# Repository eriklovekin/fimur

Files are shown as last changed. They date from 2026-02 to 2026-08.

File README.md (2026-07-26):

# Fused Inertial Measurement Unit aRray (FIMUR)
Can the performance of high-cost IMUs be matched through the fusion of a large array of MEMS IMUs?

## Coordinate Frames
### Sensor (S)
The S frame is the frame in which the sensor outputs measurements.

### Filter (F)
The F frame is the frame in which the output of the filter is represented. The origin and orientation of each IMU must be initialized in this frame. 
    Origin: position of the S origin of the IMU as (x_F, y_F, z_F)
    Rotation: Direction cosine matrix from IMU S frame to F frame

### Wake (W)
The W frame is an inertial frame colocated with the F frame at filter startup (wake). It does not move with the sensor, and is the frame in which position estimates are represented.

### ENU (L)
The ENU frame is an inertial frame with origin colocated with the Filter frame origin.

## Filters

### 1: Intuitive Filter
Naive filter that implements my intuition about how a filter should work

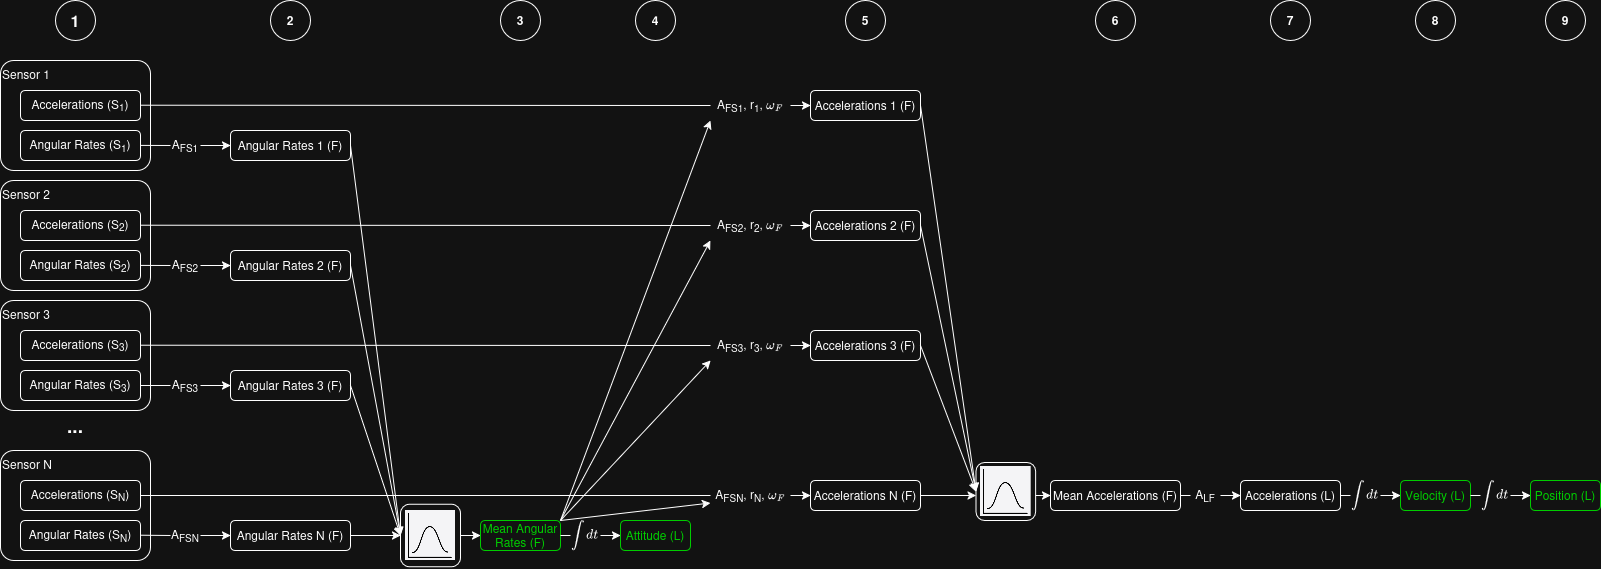
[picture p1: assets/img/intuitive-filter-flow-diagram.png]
Intuitive Filter Flow Diagram

*Figure 1: Flow diagram of Intuitive Filter*

### Dependencies

## Python
Running with python 3.12.3
Ensure the following libraries are installed using `pip install <library>`
- serial
- pyserial
- pandas
- numpy
- pyqtgraph
- pyside6
- allantools

### PyQt
- `sudo apt update`
- `sudo apt install libxcb-cursor0`

## References
1 [Interactive Kalman Filter Tutorial](https://arthurlovekin.com/interactive-kalman-filter/index.html)

2 [Extended Kalman Filter](https://mwrona.com/posts/attitude-ekf/)

3 Sarabandi, S; Thomas, F - Accurate Computation of Quaternions from Rotation Matrices

4 [Rotation Quaternions, and How to Use Them](https://danceswithcode.net/engineeringnotes/quaternions/quaternions.html)

5 [AHRS Complimenatary Filter](https://ahrs.readthedocs.io/en/latest/filters/complementary.html)

6 [Building a Virtual Gyro](https://www.nxp.com/company/about-nxp/smarter-world-blog/BL-BUILDING-VIRTUAL-GYRO)

7 [Gauss Markov Theorem](https://www.statlect.com/fundamentals-of-statistics/Gauss-Markov-theorem)

8 [Sensor Fusion for Distributed Inertial Measurement Units](https://hollydinkel.github.io/assets/pdf/AAS2025.pdf)

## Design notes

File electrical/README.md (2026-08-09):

# FIMUR Electrical
## Naming Convention
Each board has a 3-digit version number: A.B.C
A - major version number
B - board type. 
    1 is ICM20948 i2c breakout;
    2 is i2c multiplexer breakout and esp32 interface
C - minor version number

## IMC20948 Breakout (x.1.x)
I2C Breakout for two ICM20948 9-axis IMUs.
U2 (sensor on the left when text is upright) has I2C address 0x68. U3 has address 0x69.

### Exposes
- I2C bus
    two connectors to allow daisychaining
- pullup pins
    One and only one device on the bus must jump the pullup pins to allow for correct logic operation.
- FSYNC pins
    Future Work: should be able to daisychain all IMUs on this line to synchronize sample times

### v0.1.1
Works. 
- should add some capacitors to the 1.8V power supply as per spec sheet
- print IMU addresses next to them for easy ID

## Multiplexer Interface (x.2.x)
Connects ESP32 with TCA9548A I2C multiplexer.

### Exposes
- i2c bus upstream of multiplexer
    two connectors to allow daisychaining
- pullup pins for upstream i2c bus
    One and only one device on the upstream bus must jump the pullup pins to allow for correct logic operation.
- address pins for multiplexer
    each multiplexer on the upstream i2c bus must have a unique address. Addresses range from 0x70 to 0x77. The default address w/o any address pins driven is 0x70.
- eight multiplexed i2c channels downstream of the multiplexer. 
    These act as their own bus, so devices with the same address can be used if on different channels.

The board uses 3.3V I2C logic supplied directly from the ESP32.

### 0.2.1
Bad: made ESP32 get very hot. Do not use.

### 0.2.2
Fixed issues with 0.2.1. Tested with two IMUs connected to the same and differet channels.

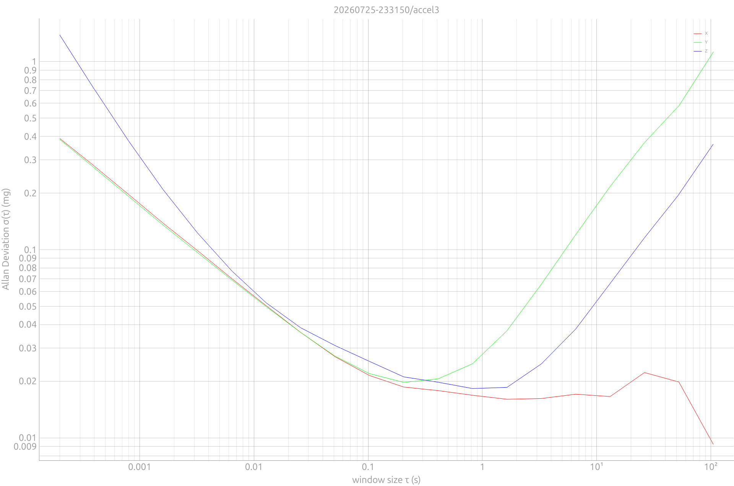
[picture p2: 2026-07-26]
assets/img/allan/20260725-233150/allan_accel3.png

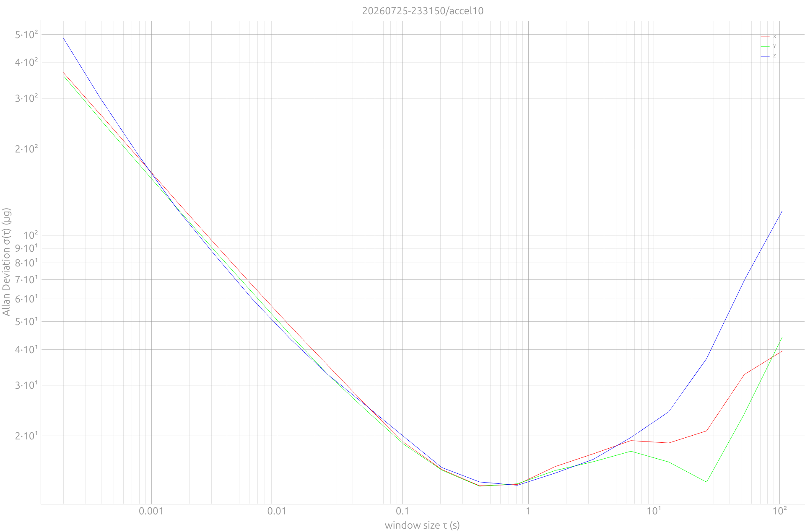
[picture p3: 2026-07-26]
assets/img/allan/20260725-233150/allan_accel10.png

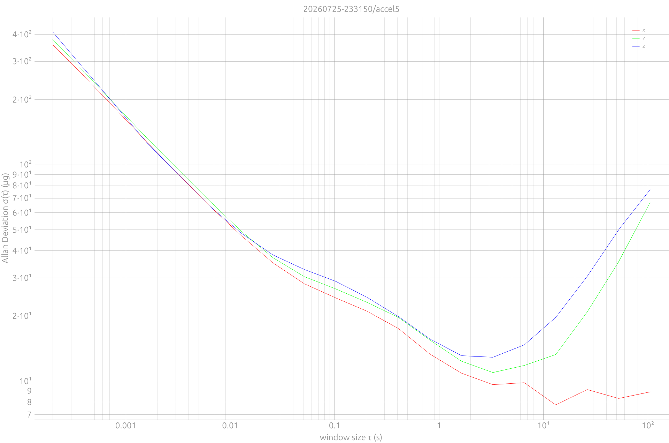
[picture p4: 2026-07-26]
assets/img/allan/20260725-233150/allan_accel5.png

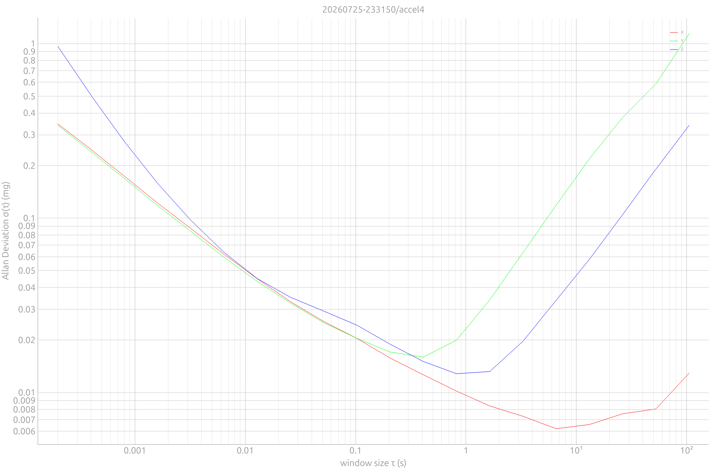
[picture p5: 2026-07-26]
assets/img/allan/20260725-233150/allan_accel4.png

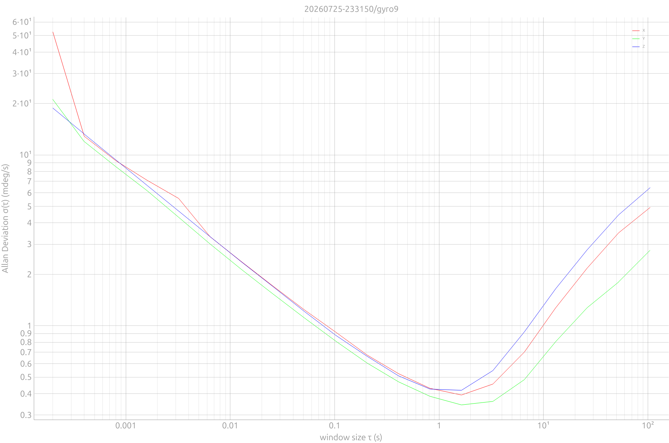
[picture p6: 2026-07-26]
assets/img/allan/20260725-233150/allan_gyro9.png

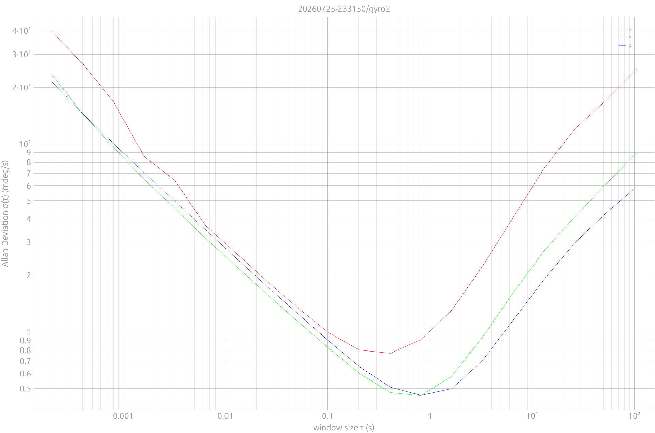
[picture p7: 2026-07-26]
assets/img/allan/20260725-233150/allan_gyro2.png

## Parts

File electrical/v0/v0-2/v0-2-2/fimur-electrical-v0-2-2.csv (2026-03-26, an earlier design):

Designator | Footprint | Comment
J7,J8,J12,J15,J10,J9,J11,J6,J14,J13 | JST_SH_SM04B-SRSS-TB_1x04-1MP_P1.00mm_Horizontal | XY-SM04B-SRSS-TB
J5,J4,J3 | PinHeader_1x03_P2.54mm_Vertical | HC-PZ254-11.5L-1x3PZ
J2,J1 | PinSocket_1x16_P2.54mm_Vertical | 2541FV-16P-B
R1,R3,R2 | R_1206_3216Metric | 10k
U1 | TSSOP-24_4.4x7.8mm_P0.65mm | TCA9548APWR
J16 | PinHeader_1x02_P2.54mm_Vertical | HC-PZ254-11.5L-1x2PZ

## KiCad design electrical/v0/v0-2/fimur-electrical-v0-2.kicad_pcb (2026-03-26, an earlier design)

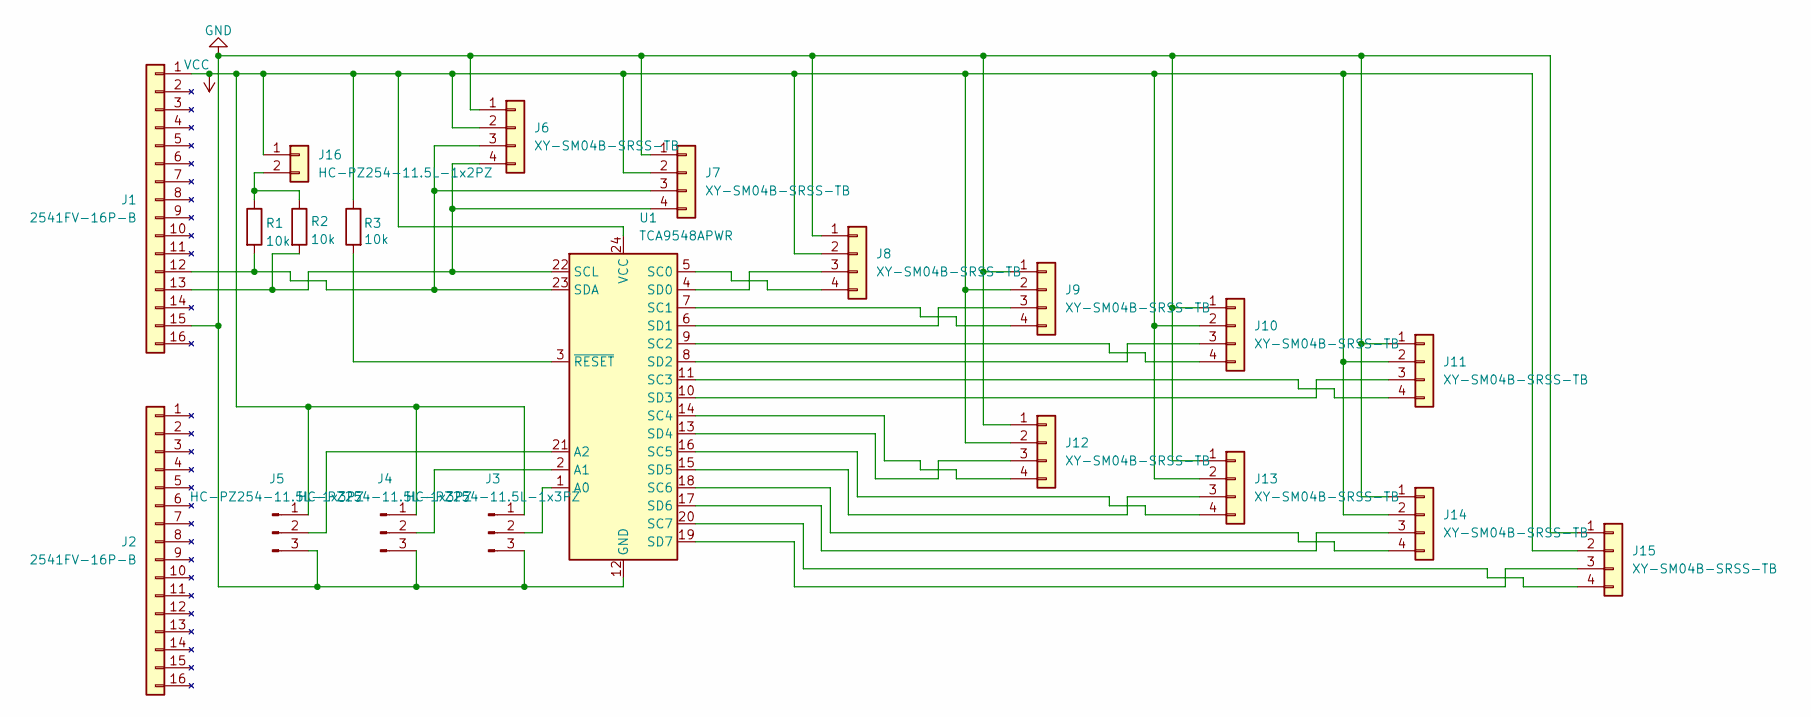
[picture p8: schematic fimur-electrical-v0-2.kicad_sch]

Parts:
J1, J2: 2541FV-16P-B; PinSocket_1x16_P2.54mm_Vertical
J3, J4, J5: HC-PZ254-11.5L-1x3PZ; PinHeader_1x03_P2.54mm_Vertical
J6, J7, J8, J9, J10, J11, J12, J13, J14, J15: XY-SM04B-SRSS-TB; JST_SH_SM04B-SRSS-TB_1x04-1MP_P1.00mm_Horizontal
J16: HC-PZ254-11.5L-1x2PZ; PinHeader_1x02_P2.54mm_Vertical
R1, R2, R3: 10k; R_1206_3216Metric
U1: TCA9548APWR; TSSOP-24_4.4x7.8mm_P0.65mm

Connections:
GND: J1.15 (G), J3.3, J4.3, J5.3, J6.1, J7.1, J8.1, J9.1, J10.1, J11.1, J12.1, J13.1, J14.1, J15.1, U1.12 (GND); also elsewhere on the board
unnamed: J1.12 (2), J6.3, J7.3, R1.2, U1.23 (SDA)
unnamed: J1.13 (3), J6.4, J7.4, R2.2, U1.22 (SCL)
unnamed: J3.2, U1.1 (A0)
unnamed: J4.2, U1.2 (A1)
unnamed: J5.2, U1.21 (A2)
unnamed: J8.3, U1.4 (SD0)
unnamed: J8.4, U1.5 (SC0)
unnamed: J9.3, U1.6 (SD1)
unnamed: J9.4, U1.7 (SC1)
unnamed: J10.3, U1.8 (SD2)
unnamed: J10.4, U1.9 (SC2)
unnamed: J11.3, U1.10 (SD3)
unnamed: J11.4, U1.11 (SC3)
unnamed: J12.3, U1.13 (SD4)
unnamed: J12.4, U1.14 (SC4)
unnamed: J13.3, U1.15 (SD5)
unnamed: J13.4, U1.16 (SC5)
unnamed: J14.3, U1.17 (SD6)
unnamed: J14.4, U1.18 (SC6)
unnamed: J15.3, U1.19 (SD7)
unnamed: J15.4, U1.20 (SC7)
unnamed: J16.2, R1.1, R2.1
unnamed: R3.2, U1.3 (~RESET)
VCC: J1.1 (3V3), J3.1, J4.1, J5.1, J6.2, J7.2, J8.2, J9.2, J10.2, J11.2, J12.2, J13.2, J14.2, J15.2, J16.1, R3.1, U1.24 (VCC); also elsewhere on the board

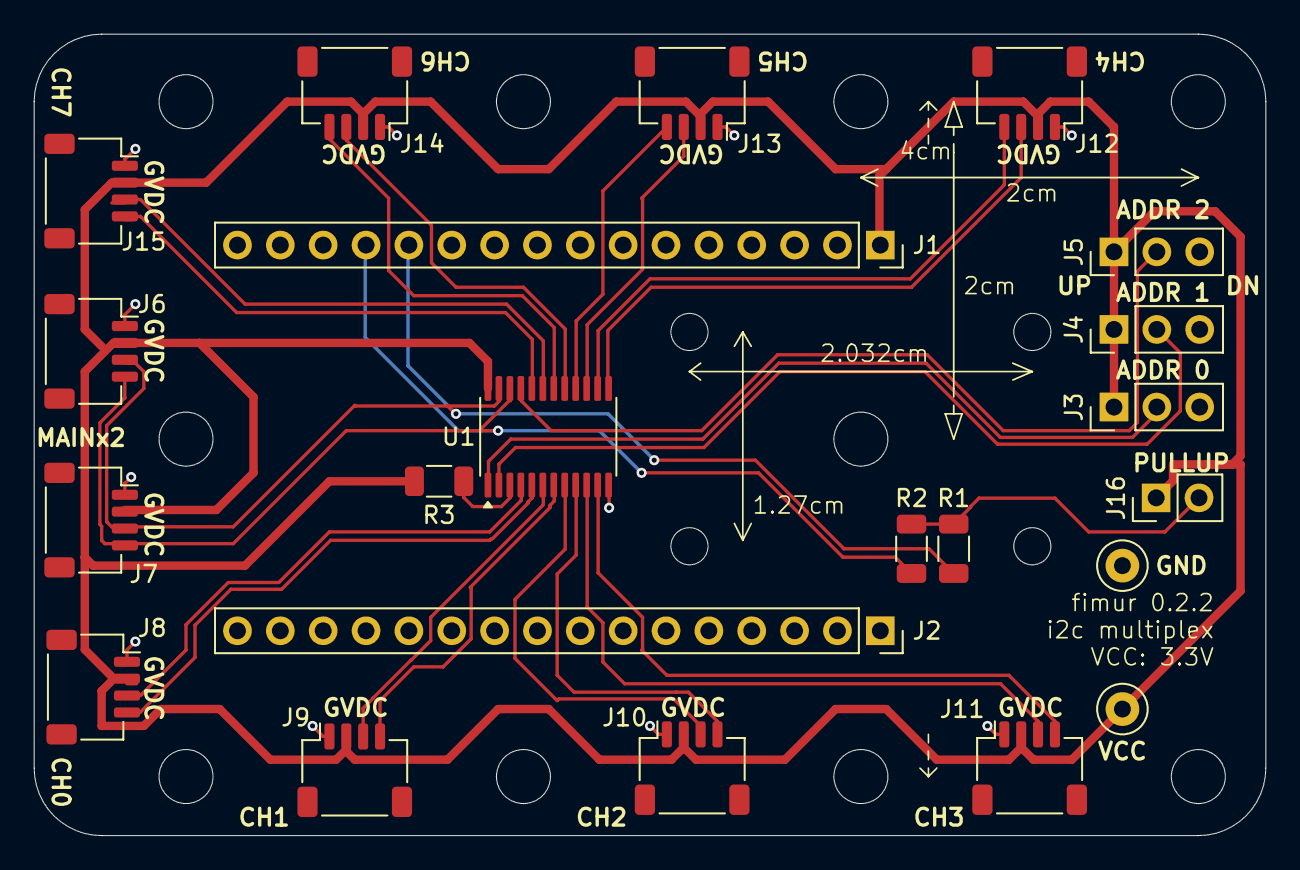
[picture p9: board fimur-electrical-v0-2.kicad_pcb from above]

Board: 2 copper layers, 73.0 x 47.5 mm, 22 parts (0 on the bottom side), 25 nets.

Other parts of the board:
GND: TestPoint_Loop_D1.80mm_Drill1.0mm_Beaded
VCC: TestPoint_Loop_D1.80mm_Drill1.0mm_Beaded

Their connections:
GND: GND.1; also elsewhere on the board
VCC: VCC.1; also elsewhere on the board

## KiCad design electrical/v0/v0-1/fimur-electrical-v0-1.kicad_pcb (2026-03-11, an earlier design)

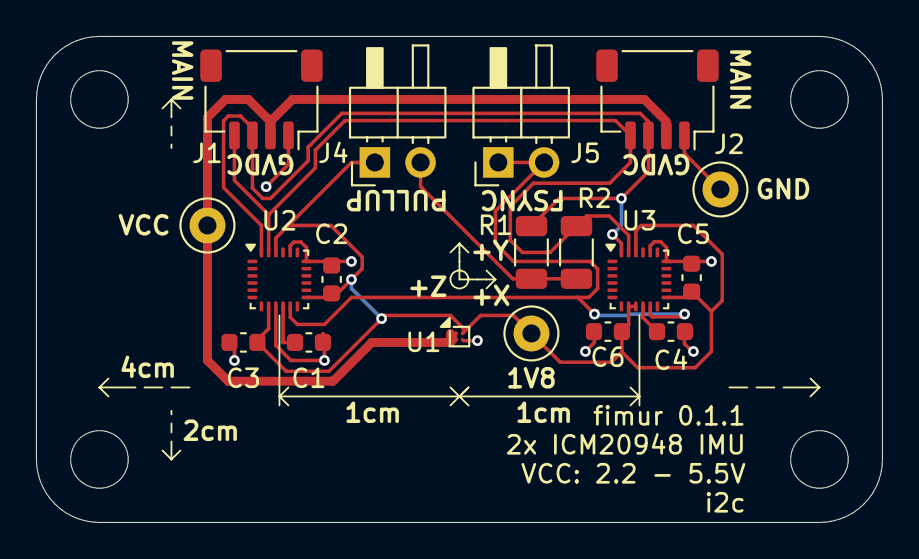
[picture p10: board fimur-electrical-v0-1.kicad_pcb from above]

Board: 2 copper layers, 47.0 x 27.0 mm, 18 parts (0 on the bottom side), 9 nets.

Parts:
1V8: TestPoint_Loop_D1.80mm_Drill1.0mm_Beaded
C1, C2, C3, C4, C5, C6: 0.1 uF; C_0603_1608Metric
GND: TestPoint_Loop_D1.80mm_Drill1.0mm_Beaded
J1, J2: Conn_01x04_Pin; JST_SH_SM04B-SRSS-TB_1x04-1MP_P1.00mm_Horizontal
J4, J5: Conn_01x02; PinHeader_1x02_P2.54mm_Horizontal
R1, R2: 10k; R_1206_3216Metric
U1: NCP163AFCS180T2G; WLCSP-4_0.64x0.64mm_Layout2x2_P0.35mm
U2, U3: ICM-20948; InvenSense_QFN-24_3x3mm_P0.4mm
VCC: TestPoint_Loop_D1.80mm_Drill1.0mm_Beaded

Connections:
GND: C1.2, C2.2, C3.2, C4.2, C5.2, C6.2, GND.1, J1.1, J2.1, U1.B2 (GND), U2.9 (SDO/AD0), U2.18 (GND), U2.20 (GND), U3.18 (GND), U3.20 (GND)
unnamed: J1.2, J2.2, U1.A1 (VIN), U1.B1 (EN), VCC.1
unnamed: J1.3, J2.3, R1.2, U2.24 (SDA/SDI), U3.24 (SDA/SDI)
unnamed: J1.4, J2.4, R2.2, U2.23 (SCL/SCLK), U3.23 (SCL/SCLK)
unnamed: 1V8.1, C2.1, C3.1, C5.1, C6.1, J4.1, U1.A2 (VOUT), U2.8 (VDDIO), U2.13 (VDD), U2.22 (~CS), U3.8 (VDDIO), U3.9 (SDO/AD0), U3.13 (VDD), U3.22 (~CS)
unnamed: J4.2, R1.1, R2.1
unnamed: J5.1, J5.2, U2.11 (FSYNC), U3.11 (FSYNC)
unnamed: C1.1, U2.10 (REGOUT)
unnamed: C4.1, U3.10 (REGOUT)

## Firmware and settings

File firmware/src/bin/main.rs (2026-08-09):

#![no_std]
#![no_main]
#![deny(
    clippy::mem_forget,
    reason = "mem::forget is generally not safe to do with esp_hal types, especially those \
    holding buffers for the duration of a data transfer."
)]
#![deny(clippy::large_stack_frames)]

use defmt::{
    info,
};
// use esp_hal::lp_core::LpCoreClockSource;
use esp_println::println;
use esp_hal::clock::CpuClock;
use esp_hal::main;
use esp_hal::rmt::Rmt;
use esp_hal::time::{Duration, Instant, Rate};
use core::cell::RefCell;
use core::fmt::Write;
use heapless::String;
use embedded_hal_bus::i2c::RefCellDevice;
use esp_hal_smartled::{SmartLedsAdapter, smart_led_buffer};
use smart_leds::{RGB8, SmartLedsWrite as _};
use {esp_backtrace as _, esp_println as _};

use esp_hal::i2c::master::{I2c, Config};

use icm20948::Icm20948;
use imu_traits::{Imu, ImuWithAdustableScale};
use fimur::filter::{
    Filter,
};

use xca9548a::{Xca9548a, SlaveAddr};
// This creates a default app-descriptor required by the esp-idf bootloader.
// For more information see: <https://docs.espressif.com/projects/esp-idf/en/stable/esp32/api-reference/system/app_image_format.html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>
esp_bootloader_esp_idf::esp_app_desc!();

#[allow(
    clippy::large_stack_frames,
    reason = "it's not unusual to allocate larger buffers etc. in main"
)]
#[main]
fn main() -> ! {
    info!("startup");

    let mut timestamp: u64 = 0;
    // let loop_duration_us: u32 = 200; 

    let config = esp_hal::Config::default().with_cpu_clock(CpuClock::max());
    let _peripherals = esp_hal::init(config);
    let rmt = Rmt::new(
        _peripherals.RMT, Rate::from_mhz(80)).unwrap();

    let i2c_config = Config::default();
    let i2c = I2c::new(_peripherals.I2C0, i2c_config)
        .expect("Failed to initialize i2c")
        .with_sda(_peripherals.GPIO2)
        .with_scl(_peripherals.GPIO3);
    // RefCell needed so multiple multiplexers or I2C devices can share the same bus
    let i2c_bus = RefCell::new(i2c);

    let aligned: [[f32;3];3]= [
        [1.0, 0.0, 0.0],
        [0.0, 1.0, 0.0],
        [0.0, 0.0, 1.0]
    ];

    let cots_aligned: [[f32;3];3]= [
        [ 0.0, -1.0,  0.0],
        [-1.0,  0.0,  0.0],
        [ 0.0,  0.0, -1.0]
    ];

    // let switch_address = SlaveAddr::Alternative(false,false,false);
    let switch_address = SlaveAddr::default();
    let i2c_switch = Xca9548a::new(
        RefCellDevice::new(&i2c_bus), switch_address);
    let parts = i2c_switch.split();
    
    // RefCell needed so multiple devices can share the same channel of the multiplexer
    let ch0_bus = RefCell::new(parts.i2c0);
    let ch1_bus = RefCell::new(parts.i2c1);
    let ch2_bus = RefCell::new(parts.i2c2);
    let ch3_bus = RefCell::new(parts.i2c3);
    let ch4_bus = RefCell::new(parts.i2c4);
    let ch5_bus = RefCell::new(parts.i2c5);
    // let ch6_bus = RefCell::new(parts.i2c6);
    // let ch7_bus = RefCell::new(parts.i2c7);

    let imu1 = Icm20948::new_with_mount(
        RefCellDevice::new(&ch0_bus),0x68,
        [-0.01,0.0,0.0],
        aligned);
    let imu2 = Icm20948::new_with_mount(
        RefCellDevice::new(&ch0_bus),0x69,
        [0.01,0.0,0.0],
        aligned);

    let imu3 = Icm20948::new_with_mount(
        RefCellDevice::new(&ch1_bus),0x68,
        [-0.01,0.0,-0.0115],
        aligned);
    let imu4 = Icm20948::new_with_mount(
        RefCellDevice::new(&ch1_bus),0x69,
        [0.01,0.0,-0.0115],
        aligned);

    let imu5 = Icm20948::new_with_mount(
        RefCellDevice::new(&ch2_bus),0x68,
        [-0.01,0.0,-0.023],
        aligned);
    let imu6 = Icm20948::new_with_mount(
        RefCellDevice::new(&ch2_bus),0x69,
        [0.01,0.0,-0.023],
        aligned);

    let imu7 = Icm20948::new_with_mount(
        RefCellDevice::new(&ch3_bus),0x68,
        [-0.01,0.0,-0.0345],
        aligned);
    let imu8 = Icm20948::new_with_mount(
        RefCellDevice::new(&ch3_bus),0x69,
        [0.01,0.0,-0.0345],
        aligned);

    let imu9 = Icm20948::new_with_mount(
        RefCellDevice::new(&ch4_bus),0x68,
        [-0.01,0.0,-0.0460],
        aligned);
    let imu10 = Icm20948::new_with_mount(
        RefCellDevice::new(&ch4_bus),0x69,
        [0.01,0.0,-0.0460],
        aligned);

    let imu11 = Icm20948::new_with_mount(
        RefCellDevice::new(&ch5_bus),0x68,
        [0.0,-0.03,0.0],
        cots_aligned);
    let imu12 = Icm20948::new_with_mount(
        RefCellDevice::new(&ch5_bus),0x69,
        [0.0,-0.03,-0.0115],
        cots_aligned);


    let mut f = Filter::new([
        imu1, imu2, imu3, imu4, imu5, imu6, 
        imu7, imu8, imu9, imu10, imu11, imu12
        ]);
    f.init();
    
    for s in 0..f.get_n_sensors() {
        f.sensor(s).set_accelerometer_scale(3)
            .expect("failed to set accelerometer range");
        f.sensor(s).set_gyroscope_scale(3)
            .expect("failed to set gyroscope range");
        f.sensor(s).set_origin_f([0.0, 0.0, 0.01]);
        f.sensor(s).set_rotation_dcm_s2f([  
            [1.0, 0.0, 0.0],
            [0.0, 1.0, 0.0],
            [0.0, 0.0, 1.0]]);
    }
    
    let mut led_buf = smart_led_buffer!(1);
    let mut led = SmartLedsAdapter::new(
        rmt.channel0, _peripherals.GPIO8, &mut led_buf);
    const LEVEL: u8 = 10;
    let mut color = RGB8::default();
    color.r = LEVEL;

    let mut output: String<8192> = String::new();

    info!("reading imu data");
    loop {
        led.write([color].into_iter()).unwrap();
        let loop_start = Instant::now();
        // while delay_start.elapsed() < Duration::from_micros(loop_duration_us as u64) {}

        // Read all sensors
        f.read_all();

        // Estimate virtual measurements
        f.colocated_coaligned_avg();
        // f.f_frame_avg();

        output.clear();
        write!(output,"{},",timestamp).ok();
        write!(output,"{}", f.report_raw()).ok();
        write!(output,"{}", f.report_virtual_meas()).ok();
        println!("{}",output);
        let tmp = color.r;
        color.r = color.b;
        color.b = color.g;
        color.g = tmp;

        let loop_end = Instant::now();
        let elapsed: Duration = loop_end - loop_start;
        timestamp += elapsed.as_micros();
    }
}

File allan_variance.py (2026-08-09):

import pandas as pd
import numpy as np
import pyqtgraph as pg
from pyqtgraph.Qt import QtWidgets, QtCore
import pyqtgraph.exporters
import sys
import os
import signal
import allantools

def compute_allan_variance(dt,x):
    N = len(x)
    avar = []
    tau = []
    vals = []
    n = 1
    r = 1.1
    while n < N//2:
        vals.append(n)
        n_next = n*r
        n = int(np.round(max(n_next, n+1)))

    j=0
    for n in vals:
        print(f"{100*j/len(vals):.2f}% complete")
        A = 1/(2*n**2*dt**2*(N-2*n))
        d = x[2*n:]-2*x[n:-n] + x[:-2*n]
        avar.append(A*np.sum(d**2))

        tau.append(n*dt) 
        j+=1
    return tau, avar

if __name__ == "__main__":
    path = "./logs/"
    timestamp = "20260808-235938/"
    # timestamp = "20260725-233150/"
    # timestamp = "20260807-052335/"
    sensor = ["accel", "gyro"]
    units =  ["m/s2", "rad/s"]
    axis = ["x","y","z"]
    color = ["r","g","b"]
    N_IMUS = 13

    index = pd.MultiIndex.from_product(
    [range(1, N_IMUS+1), ["accel", "gyro"], ["x", "y", "z"]],
    names=["imu", "sensor", "axis"]
    )
    superDf = pd.DataFrame(index=index, columns=["tau", "B"], dtype=float)

    # conversion from min allan deviation to bias instability
    C = 1/np.sqrt(2*np.log(2)/np.pi) # per IEEE-STD-952-1997 Annex C 

    dt_diag = []

    app = QtWidgets.QApplication(sys.argv)
    windows = []

    for i in range(0,N_IMUS):
        for j in range(len(sensor)):
            full = path+timestamp+sensor[j]+str(i+1)+".csv"
            print(f"loading {full}")
            df = pd.read_csv(f"{full}")

            z_numeric = pd.to_numeric(df["z"], errors="coerce")
            bad_mask = z_numeric.isna() & df["z"].notna()  # failed to parse, but wasn't already NaN/empty
            # print(df.loc[bad_mask, "z"])
            
            nan_counts = df.isna().sum()
            if nan_counts.any():
                print(df.isna().sum())  # NaN count per column
                nan_rows = df[df.isna().any(axis=1)]
                print(nan_rows.head(20))
                print(f"first NaN at row: {nan_rows.index.min() if len(nan_rows) else 'none'}")
            # dt = (df["t_us"][2] - df["t_us"][1])/1e6
            dt = (df["t_us"][-1] - df["t_us"][1])/(1e6*(df["t_us"].size()-1))
            dt_diag = np.diff(df["t_us"])
            mean_dt = np.mean(dt_diag)
            std_dt = np.std(dt_diag)
            w = pg.GraphicsLayoutWidget(show=True, title=f"Loop Time histogram - {timestamp}{sensor[j]}{i+1}")
            w.resize(1200, 800)
            p1 = w.addPlot()
            p1.setTitle(f"Loop Time histogram - {timestamp}{sensor[j]}{i+1}, mean: {mean_dt}, std: {std_dt}")
            # p1.setLabel('left', '', units="s")
            p1.setLabel('bottom', 'Loop time', units="s")
            y, x = np.histogram(dt_diag, bins=30)
            p1.PlotCurveItem(x,y,stepMode=True, fillLevel=0, brush=(0, 150, 255, 150), pen='k')

            win = pg.GraphicsLayoutWidget(show=True, title=f"Allan Variance - {timestamp}{sensor[j]}{i+1}")
            win.resize(1200, 800)

            p = win.addPlot()
            p.setTitle(f"{timestamp}{sensor[j]}{i+1}")
            p.setLabel('left', 'Allan Deviation &sigma;(&tau;)', units=f"{units[j]}")
            p.setLabel('bottom', 'window size &tau;', units='s')
            ax = p.getAxis('left')
            ax.enableAutoSIPrefix(False)
            p.addLegend(offset = (-10,10))
            p.setLogMode(x=True, y=True)
            p.showGrid(x=True, y=True)
            
            for a in range(len(axis)):
                raw = df[axis[a]].to_numpy()

                tau, adev, adev_err, n = allantools.oadev(
                    raw, rate=1/dt, data_type="freq", taus="octave"
                )

                # print(f"{axis[a]}-axis...")
                # craw = np.cumsum(raw) * dt
                # tau, avar = compute_allan_variance(dt,craw)
                # adev = np.sqrt(avar)
                # print(f"{type(adev)}, {np.shape(adev)}")
                min_adev = np.min(adev)
                idx = np.argmin(np.abs(adev - min_adev))
                t = tau[idx]
                B = C*min_adev
                superDf.loc[(i+1,f"{sensor[j]}",f"{axis[a]}"),"tau"] = t
                superDf.loc[(i+1,f"{sensor[j]}",f"{axis[a]}"),"B"] = B

                print(f"{axis[a]}:\nmin adev [{units[j]}]: {min_adev:.4f}, " \
                      f"bias instability [{units[j]}]: {B:.4f}, " \
                      f"time constant: {t:.4f}")

                p.plot(tau,adev,pen=f"{color[a]}", name=f"{axis[a]}")
                # err_item = pg.ErrorBarItem(
                #     x=np.log10(tau_x),
                #     y=np.log10(adev_x),
                #     top=np.log10(adev_x + adev_err_x) - np.log10(adev_x),
                #     bottom=np.log10(adev_x) - np.log10(adev_x - adev_err_x),
                #     pen=pg.mkPen('r', width=1)
                # )
                # p.addItem(err_item)

            win.show()
            windows.append(win)

            for _ in range(10):
                app.processEvents()

            expath = f"./assets/img/allan/{timestamp}"
            exname = f"{expath}allan_{sensor[j]}{i+1}.png"

            # os.makedirs(expath, exist_ok=True)
            # exporter = pg.exporters.ImageExporter(p)
            # exporter.parameters()['width'] = 1920
            # exporter.parameters()['background'] = 'w'
            # print(f"writing to {exname}")
            # exporter.export(f"{exname}")

    print("Stack stats:")
    for j in range(len(sensor)):
        print(f"{sensor[j]}")
        for a in range(len(axis)):
            set = superDf.xs((sensor[j],axis[a]), level=("sensor","axis"))
            meanB = set["B"].mean()
            medB = set["B"].median()
            stdB = set["B"].std()
            meanTau = set["tau"].mean()
            medTau = set["tau"].median()
            stdTau = set["tau"].std()
            
            print(f"{axis[a]}")
            print(f"bias instability mean [{units[j]}]: {meanB:.4f}, median: {medB:.4f}, std: {stdB:.4f}")
            print(f"correlation time mean [{units[j]}]: {meanTau:.4f}, median: {medTau:.4f}, std: {stdTau:.4f}")
        print("\n")

    print("plotting...")
    # Let Ctrl+C interrupt the Qt event loop
    signal.signal(signal.SIGINT, signal.SIG_DFL)

    timer = QtCore.QTimer()
    timer.timeout.connect(lambda: None)  # no-op, just wakes the interpreter
    timer.start(200)  # ms

    try:
        sys.exit(app.exec())
    except KeyboardInterrupt:
        print("Ctrl+C received, closing windows...")
        for w in windows:
            w.close()
        app.quit()

    # print(f"Mean dt [us]: {mean_dt_us}, std: {std_dt_us}")

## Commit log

2025-12-28 reading raw values from encoder
2025-12-28 reading encoder angles in degrees
2025-12-28 cleanup encoder reading
2026-02-09 reorganization into crates
    [fimur-electrical.kicad_pcb, fimur-electrical.kicad_sch]
2026-02-18 added all register banks to icm driver
2026-02-18 imu-traits and icm crates added to workspace Cargo.toml and Cargo.lock
2026-02-18 icm implementations of imu-traits
2026-02-18 added icm and imu-traits crates to firmware dependencies
2026-02-20 reading imu telemetry!
2026-02-20 live qt plots of accel and gyro data
2026-02-20 auto-find port connected to esp32
2026-02-21 estimate attitude by integrating raw gyroscope data
2026-02-21 functions to read accel in mps2 and G; functions to read gyro in dps and rps
2026-02-22 estimating velocity and attitude by direct integration; working poorly; added velocity and position plots
2026-02-25 accel and gyro scale setters and getters implemented and build:
2026-02-27 added select_register_bank to sensor reading functions
2026-03-02 2-imu pcb schematic and layout
    [fimur-electrical-v0-1.kicad_pcb, fimur-electrical-v0-1.kicad_sch]
2026-03-03 i2c multiplexer board schematic
    [fimur-electrical-v0-1.kicad_pcb, fimur-electrical-v0-1.kicad_sch, fimur-electrical-v0-2.kicad_pcb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]
2026-03-05 multiplex schematic and layout and standardization with 2-imu board
    [fimur-electrical-v0-1.kicad_pcb, fimur-electrical-v0-1.kicad_sch, fimur-electrical-v0-2.kicad_pcb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]
2026-03-07 cleanup of v10.1.1
    [fimur-electrical-v0-1.kicad_pcb, fimur-electrical-v0-1.kicad_sch]
2026-03-11 all kicad files for v0 boards
    [fimur-electrical-v0-1-B_Cu.gbr, fimur-electrical-v0-1-B_Mask.gbr, fimur-electrical-v0-1-B_Paste.gbr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]
2026-03-11 major cleanup of kicad fluff
    [fimur-electrical-v0-1-B_Cu.gbr, fimur-electrical-v0-1-B_Mask.gbr, fimur-electrical-v0-1-B_Paste.gbr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]
2026-03-13 initializing two imus on same i2c bus
2026-03-13 printing data from both imus
2026-03-13 plotting data from two imus
2026-03-26 v2 of multiplex board
    [fimur-electrical-v0-2-2.csv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]
2026-03-26 sensor mount members and utility functions
2026-04-21 store DCM insteadof quaternion; start of Filter struct
2026-04-21 generic average filters
2026-05-02 basic complimentary filter for attitude
2026-05-20 lots of syntax fixes to get it building again
    [filter.rs, lib.rs, main.rs]
2026-05-28 started integrating Filter into main; does not build
2026-05-29 cleanup many compile warnings and use filter report_raw
2026-06-09 added intuitive filter flow diagram
2026-06-09 reports of current estimated state
2026-06-27 state transition as part of Kalman filter
2026-07-09 most basic filter possible
2026-07-13 commented out things that were crashing and unused
    [filter.rs, lib.rs, main.rs]
2026-07-25 plot x accelerometer allan variance
2026-07-26 include of i2c multiplexer compiles
2026-07-26 readme for imu breakout board
2026-07-26 running with 4 IMUs
2026-07-26 reading 12 imus
2026-07-26 logging raw data from 12 imus
2026-07-26 allan variance tables for 12 imus
2026-07-29 pcb improvement suggestions
2026-08-09 added sensor positions
2026-08-09 storing metric base units for imu measurements
2026-08-09 logging raw and virtual imu; logging real timestamp rather than ideal
2026-08-09 using f64 timestamps to avoid overflow; plot histogram of timestamps as part of allan_variance
    [allan_variance.py, main.rs]
